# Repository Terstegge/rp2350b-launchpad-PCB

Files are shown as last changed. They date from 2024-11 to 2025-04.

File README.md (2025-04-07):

# RP2350 Launchpad

This repository contains the KiCad design files for a TI-style Launchpad
board with the RP2350B microcontroller. The board has the following
features:

- RP2350 microcontroller with 48 GPIOs (8 of these can be used as ADC inputs)
- 8MB of flash and 8MB of PSRAM
- A single red LED (connected to GPIO 38). Can be disabled with a jumper.
- Eight WS2812 RGB LEDs (connected to GPIO 39)
- A reset button
- Two user buttons (S1/S2 connected to GPIO 28/29)
- USB-C socket connected to the target RP2350
- A small button to let the RP2350 start in mass-storage mode for programming.
  This is usually not needed when using the debugger.
- A target isolation jumper block which can be used to completely disconnect
  the targer from power supply and debugging signals.
- A RP2040-based picoprobe debug probe which also forwards UART traffic from
  the target to the connected PC. Three LEDs signal UART RX/TX activity
  and SWD activity.
- Additional header for unused GPIOs of the picoprobe RP2040, which could
  be used for logic analyzer inputs or other purposes.
- Flexible power supply by either using
  * the upper USB-C socket connected to the debugger
  * a connected 3,7V LiPo battery
  * the lower USB-C socket connected to the target

  These three options are selectble with a small switch
- Integrated LiPo charger. The battery will be charged when the board is
  powered from the upper USB-C socket. Charging is signalled with a LED.
  The battery voltage can be read by the RP2350 using ADC channel 7.
- In all power scenarios, 3.3V and 5V are available. When using the
  battery as the power source, the 5V supply is generated with a step-up
  converter.

Why was this board designed? I have been using the MSP432 Launchpad from TI for
quite a while in university classes teaching microcontroller technology.
Unfortunately TI has stopped producing all MSP432-related products. Still we
have lots of TI boosterpack-boards like the Educational Boosterpack MK II.
To be able to use these Boosterpacks also in the future, a new Launchpad had
to be found or designed. The RP2350B is a very interesting microcontroller,
and, what is quite important for educational purposes, it has excellent
documentation. So this board came to life. As far as I know this is the only
RP2350 board including a picoprobe debugger, which makes programming for the
students a lot easier.

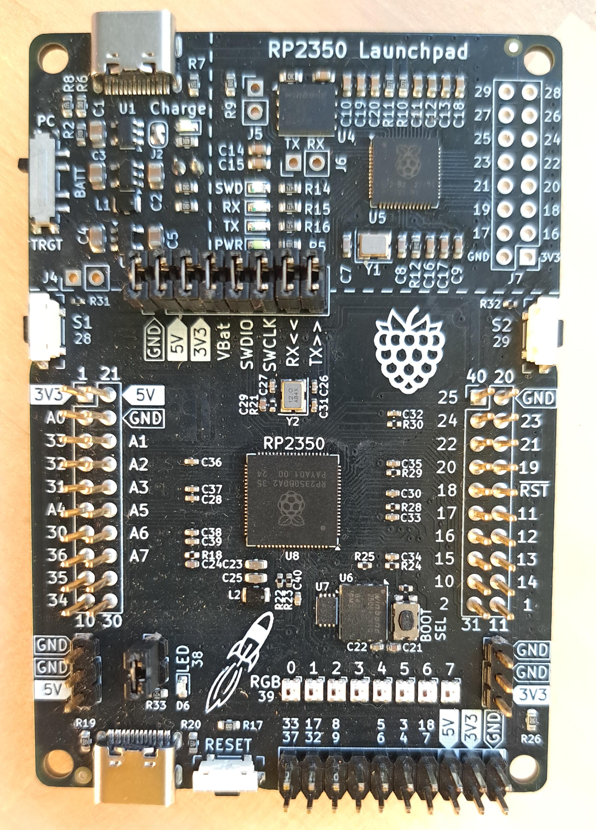
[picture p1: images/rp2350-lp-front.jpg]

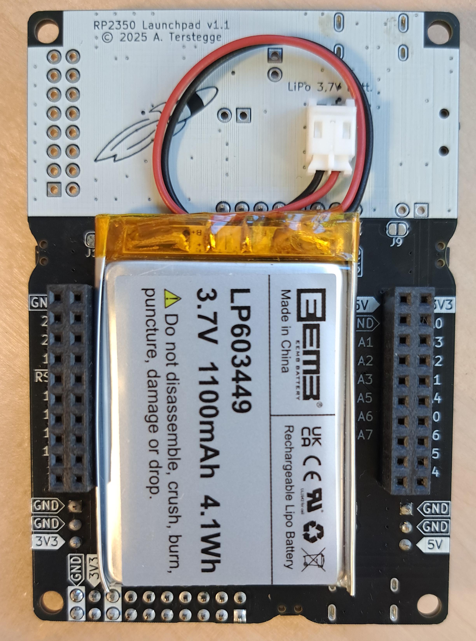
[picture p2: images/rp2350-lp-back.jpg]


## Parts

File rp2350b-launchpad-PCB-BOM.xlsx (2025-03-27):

Comment | Designator | Footprint | JLCPCB Part #
22u | C1,C2,C3,C4,C5 | Capacitor_SMD:C_0805_2012Metric | C45783
100nF | C6,C9,C10,C14,C15,C16,C17,C18,C19,C20 | Capacitor_SMD:C_0603_1608Metric | C14663
15pF | C7,C8 | Capacitor_SMD:C_0603_1608Metric | C1644
1uF | C11,C12,C13 | Capacitor_SMD:C_0603_1608Metric | C15849
4u7 | C21,C24,C29 | Capacitor_SMD:C_0402_1005Metric | C23733
100nF | C22,C28,C30,C31,C32,C33,C34,C35,C36,C37,C38,C39,C40 | Capacitor_SMD:C_0402_1005Metric | C1525
4u7 | C23,C25 | Capacitor_SMD:C_0603_1608Metric | C19666
15pF | C26,C27 | Capacitor_SMD:C_0402_1005Metric | C1548
Charge | D1 | LED_SMD:LED_0603_1608Metric | C84269
PWR | D2 | LED_SMD:LED_0603_1608Metric | C84269
LED BLUE | D3 | LED_SMD:LED_0603_1608Metric | C2288
LED GREEN | D4 | LED_SMD:LED_0603_1608Metric | C12624
LED RED | D5 | LED_SMD:LED_0603_1608Metric | C2286
LED | D6 | LED_SMD:LED_0603_1608Metric | C2286
4u7 | L1,L2 | rp2350b-launchpad-PCB:AOTA-B201610S3R3-101-T | C42411119
2k | R1,R2,R5 | Resistor_SMD:R_0603_1608Metric | C22975
100k | R3,R4,R6,R17 | Resistor_SMD:R_0603_1608Metric | C25803
5k1 | R7,R8,R19,R20 | Resistor_SMD:R_0603_1608Metric | C23186
1k | R9,R12 | Resistor_SMD:R_0603_1608Metric | C21190
27 | R10,R11 | Resistor_SMD:R_0603_1608Metric | C25190
10k | R13,R26 | Resistor_SMD:R_0603_1608Metric | C25804
470 | R14,R15,R16,R33 | Resistor_SMD:R_0603_1608Metric | C23179
33 | R18 | Resistor_SMD:R_0402_1005Metric | C25161
1k | R21,R27,R28,R29,R30,R31,R32 | Resistor_SMD:R_0402_1005Metric | C11702
27 | R22,R23 | Resistor_SMD:R_0402_1005Metric | C137890
10k | R24,R25 | Resistor_SMD:R_0402_1005Metric | C25531
S1 | S1 | rp2350b-launchpad-PCB:DIPT-1188E | C240289
S2 | S2 | rp2350b-launchpad-PCB:DIPT-1188E | C240289
Power Select | SW1 | rp2350b-launchpad-PCB:PCM13SMTR | C221842
RESET | SW2 | rp2350b-launchpad-PCB:DIPT-1188E | C240289
BOOT | SW3 | rp2350b-launchpad-PCB:KMR2-Switch | C221680
MCP73831 | U1 | Package_TO_SOT_SMD:SOT-23-5 | C424093
XC9142B50C | U2 | Package_TO_SOT_SMD:SOT-23-5 | C2468807
XC6220B33 | U3 | Package_TO_SOT_SMD:SOT-23-5 | C22466451
25Q32 | U4 | Package_SON:WSON-8-1EP_6x5mm_P1.27mm_EP3.4x4.3mm | C571260
RP2040 | U5 | Package_DFN_QFN:QFN-56-1EP_7x7mm_P0.4mm_EP3.2x3.2mm | C2040
25Q64 | U6 | Package_SON:WSON-8-1EP_6x5mm_P1.27mm_EP3.4x4.3mm | C2940197
APS6404L-3SQR | U7 | Package_SON:Winbond_USON-8-1EP_3x2mm_P0.5mm_EP0.2x1.6mm | C3040877
RP2350_80QFN | U8 | Package_DFN_QFN:QFN-80-1EP_10x10mm_P0.4mm_EP3.4x3.4mm_ThermalVias | C42415655
WS2812B-2020 | U9,U10,U11,U12,U13,U14,U15,U16 | rp2350b-launchpad-PCB:WS2812B-2020 | C965555
USB-C Connector | USB1,USB2 | rp2350b-launchpad-PCB:GT-USB-7010B | C2837092
12MHz | Y1,Y2 | Crystal:Crystal_SMD_Abracon_ABM8AIG-4Pin_3.2x2.5mm | C20625731

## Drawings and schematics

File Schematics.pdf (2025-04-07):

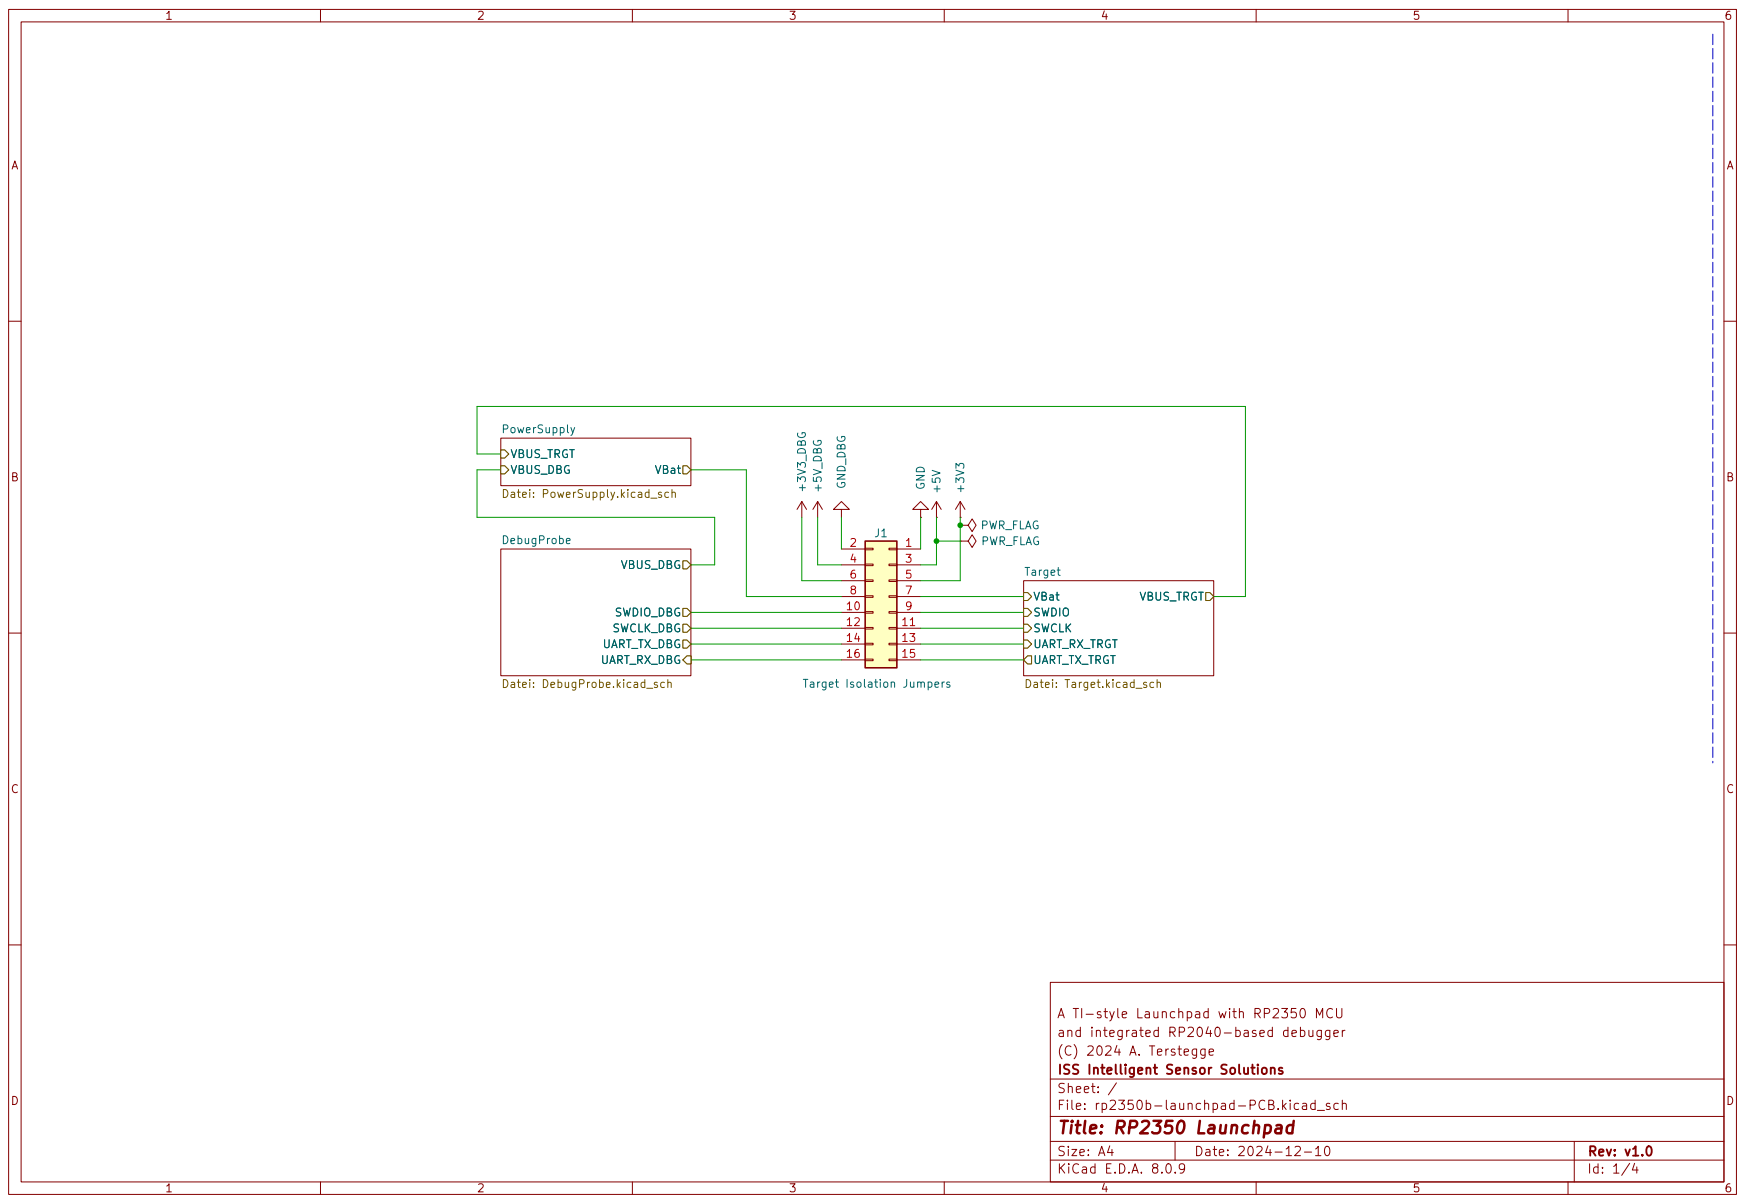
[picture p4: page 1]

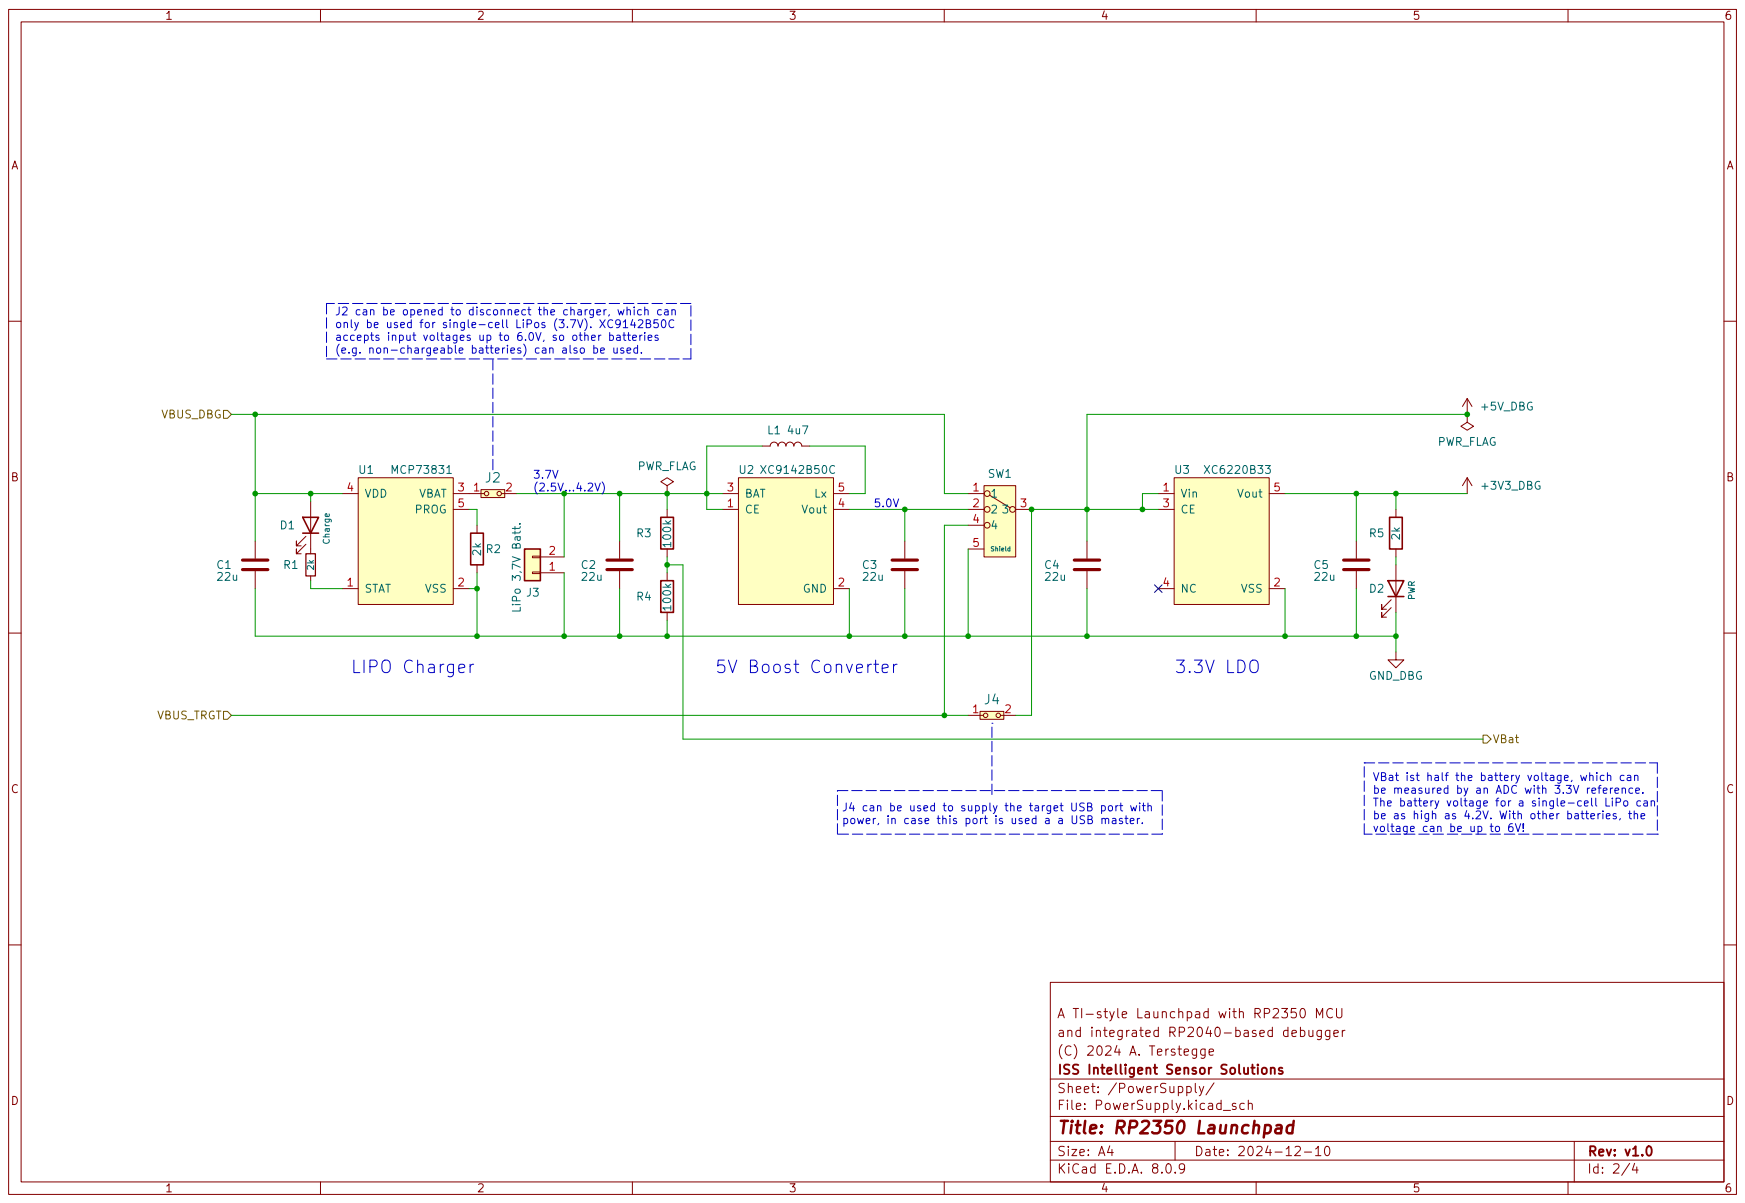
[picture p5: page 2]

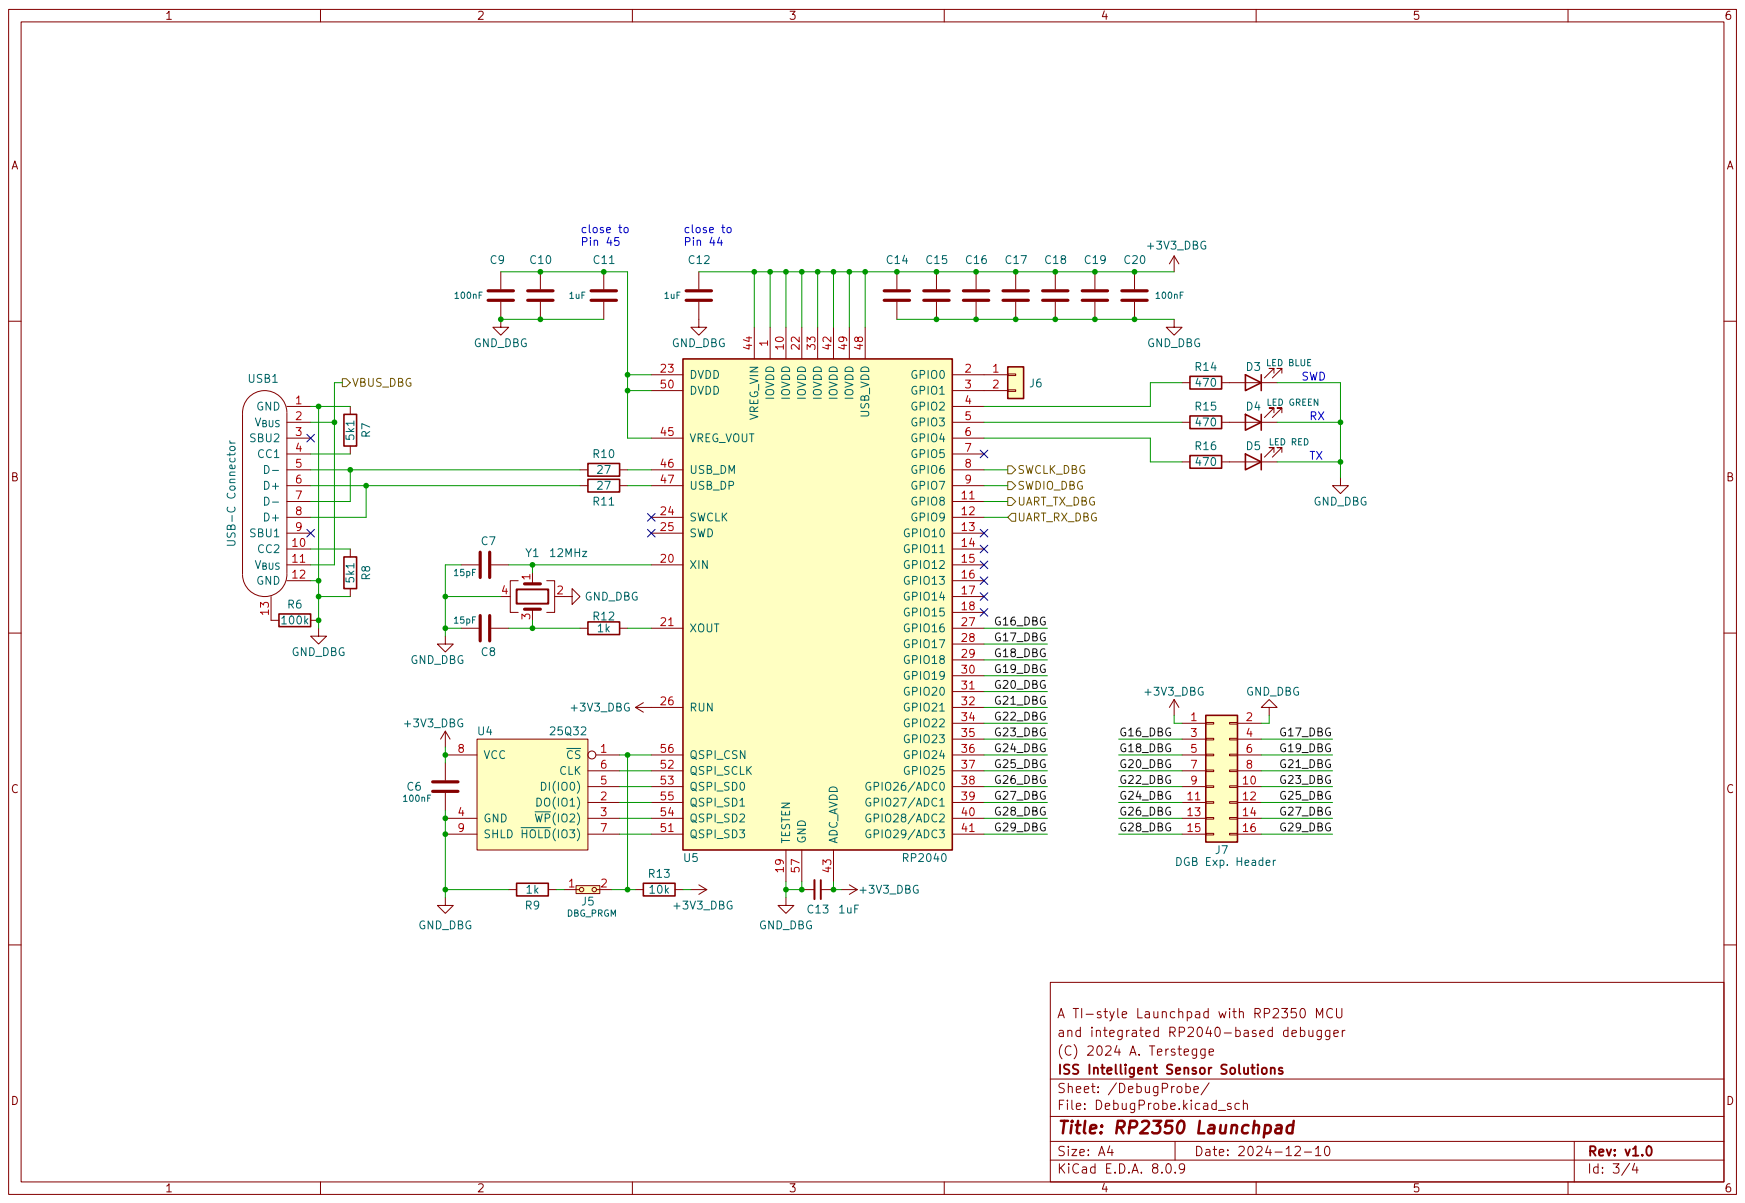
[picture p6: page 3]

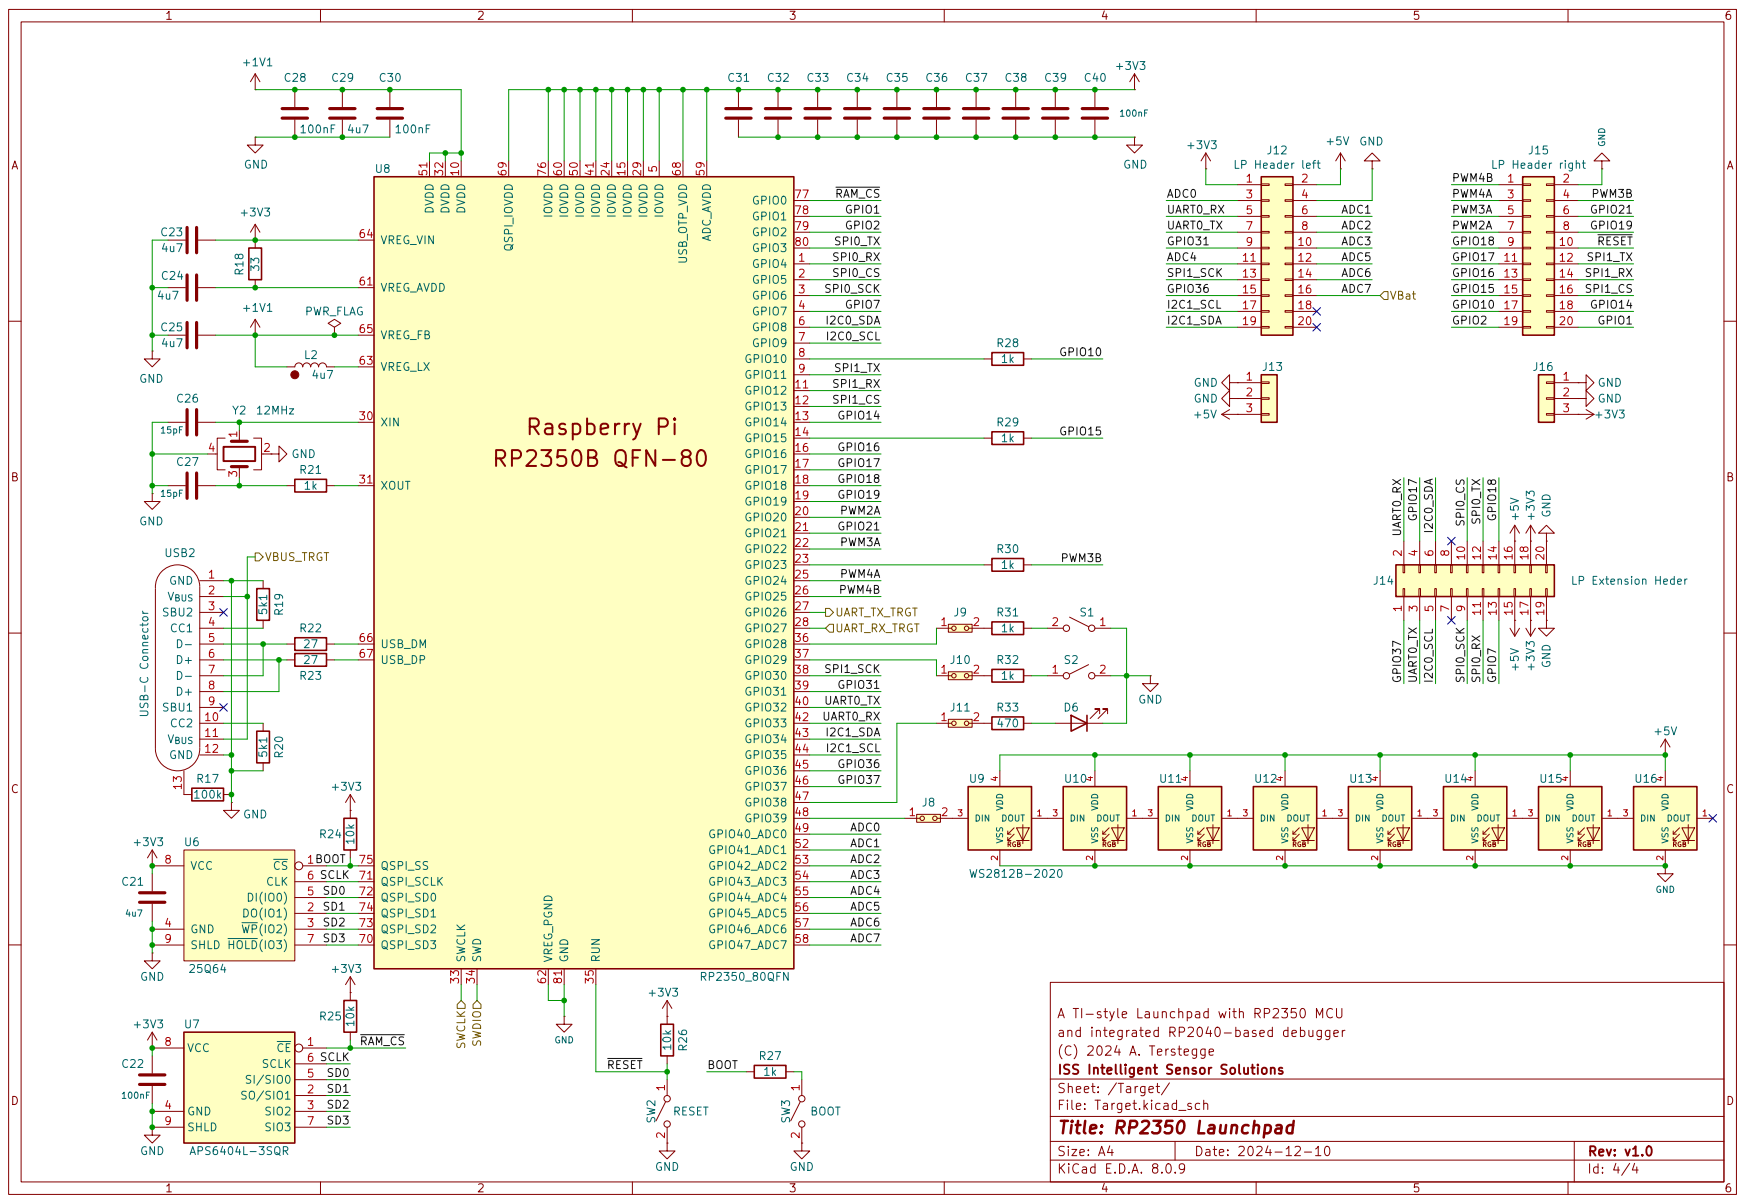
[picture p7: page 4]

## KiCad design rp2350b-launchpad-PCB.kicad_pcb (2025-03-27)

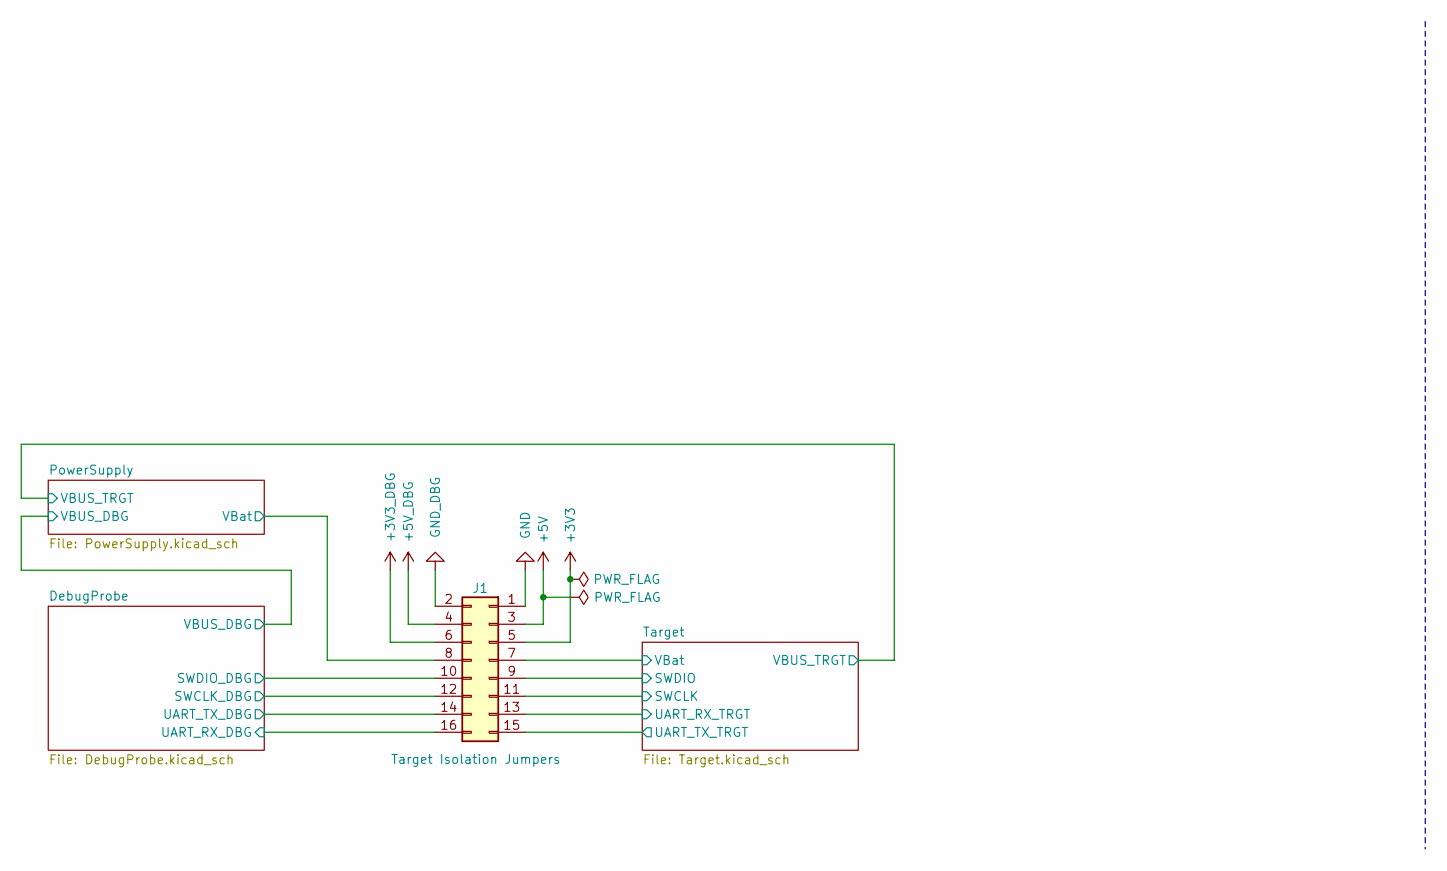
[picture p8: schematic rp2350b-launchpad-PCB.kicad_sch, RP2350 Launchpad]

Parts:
J1: Target Isolation Jumpers; PinHeader_2x08_P2.54mm_Vertical

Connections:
+3V3: J1.5; also elsewhere on the board
+3V3_DBG: J1.6; also elsewhere on the board
+5V: J1.3; also elsewhere on the board
+5V_DBG: J1.4; also elsewhere on the board
/DebugProbe/SWCLK_DBG: J1.12; also elsewhere on the board
/DebugProbe/SWDIO_DBG: J1.10; also elsewhere on the board
/DebugProbe/UART_RX_DBG: J1.16; also elsewhere on the board
/DebugProbe/UART_TX_DBG: J1.14; also elsewhere on the board
/PowerSupply/VBat: J1.8; also elsewhere on the board
/Target/ADC7: J1.7; also elsewhere on the board
/Target/SWCLK: J1.11; also elsewhere on the board
/Target/SWDIO: J1.9; also elsewhere on the board
/Target/UART_RX_TRGT: J1.13; also elsewhere on the board
/Target/UART_TX_TRGT: J1.15; also elsewhere on the board
GND: J1.1; also elsewhere on the board
GND_DBG: J1.2; also elsewhere on the board

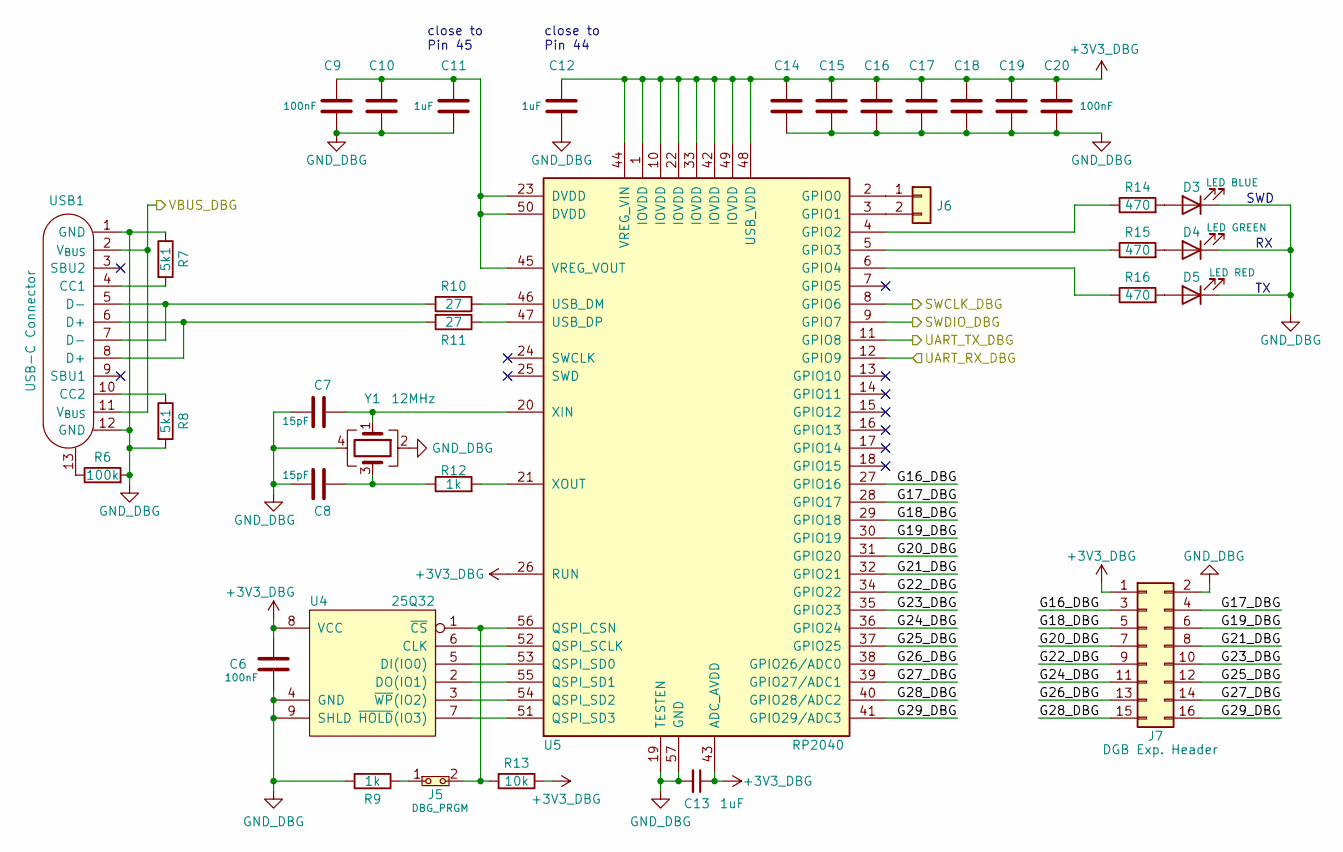
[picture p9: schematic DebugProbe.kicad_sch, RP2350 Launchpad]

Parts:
C6, C9, C10, C14, C15, C16, C17, C18, C19, C20: 100nF; C_0603_1608Metric; JLCPCB Part # C14663
C7, C8: 15pF; C_0603_1608Metric; JLCPCB Part # C1644
C11, C12, C13: 1uF; C_0603_1608Metric; JLCPCB Part # C15849
D3: LED BLUE; LED_0603_1608Metric; JLCPCB Part # C2288
D4: LED GREEN; LED_0603_1608Metric; JLCPCB Part # C12624
D5: LED RED; LED_0603_1608Metric; JLCPCB Part # C2286
J5: DBG_PRGM; PinHeader_1x02_P2.54mm_Vertical
J6: UART_DBG; PinHeader_1x02_P2.54mm_Vertical
J7: DGB Exp. Header; PinHeader_2x08_P2.54mm_Vertical
R6: 100k; R_0603_1608Metric; JLCPCB Part # C25803
R7, R8: 5k1; R_0603_1608Metric; JLCPCB Part # C23186
R9, R12: 1k; R_0603_1608Metric; JLCPCB Part # C21190
R10, R11: 27; R_0603_1608Metric; JLCPCB Part # C25190
R13: 10k; R_0603_1608Metric; JLCPCB Part # C25804
R14, R15, R16: 470; R_0603_1608Metric; JLCPCB Part # C23179
U4: 25Q32; WSON-8-1EP_6x5mm_P1.27mm_EP3.4x4.3mm; JLCPCB Part # C571260
U5: RP2040; QFN-56-1EP_7x7mm_P0.4mm_EP3.2x3.2mm; PARTREV 1.6.1; JLCPCB Part # C2040
USB1: USB-C Connector; GT-USB-7010B; JLCPCB Part # C2837092
Y1: 12MHz; Crystal_SMD_Abracon_ABM8AIG-4Pin_3.2x2.5mm; JLCPCB Part # C20625731

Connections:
+3V3_DBG: C6.1, C12.1, C13.1, C14.1, C15.1, C16.1, C17.1, C18.1, C19.1, C20.1, J7.1, R13.1, U4.8 (VCC), U5.1 (IOVDD), U5.10 (IOVDD), U5.22 (IOVDD), U5.26 (RUN), U5.33 (IOVDD), U5.42 (IOVDD), U5.43 (ADC_AVDD), U5.44 (VREG_VIN), U5.48 (USB_VDD), U5.49 (IOVDD); also elsewhere on the board
/DebugProbe/G16_DBG: J7.3, U5.27 (GPIO16)
/DebugProbe/G17_DBG: J7.4, U5.28 (GPIO17)
/DebugProbe/G18_DBG: J7.5, U5.29 (GPIO18)
/DebugProbe/G19_DBG: J7.6, U5.30 (GPIO19)
/DebugProbe/G20_DBG: J7.7, U5.31 (GPIO20)
/DebugProbe/G21_DBG: J7.8, U5.32 (GPIO21)
/DebugProbe/G22_DBG: J7.9, U5.34 (GPIO22)
/DebugProbe/G23_DBG: J7.10, U5.35 (GPIO23)
/DebugProbe/G24_DBG: J7.11, U5.36 (GPIO24)
/DebugProbe/G25_DBG: J7.12, U5.37 (GPIO25)
/DebugProbe/G26_DBG: J7.13, U5.38 (GPIO26/ADC0)
/DebugProbe/G27_DBG: J7.14, U5.39 (GPIO27/ADC1)
/DebugProbe/G28_DBG: J7.15, U5.40 (GPIO28/ADC2)
/DebugProbe/G29_DBG: J7.16, U5.41 (GPIO29/ADC3)
/DebugProbe/SWCLK_DBG: U5.8 (GPIO6); also elsewhere on the board
/DebugProbe/SWDIO_DBG: U5.9 (GPIO7); also elsewhere on the board
/DebugProbe/UART_RX_DBG: U5.12 (GPIO9); also elsewhere on the board
/DebugProbe/UART_TX_DBG: U5.11 (GPIO8); also elsewhere on the board
/DebugProbe/VBUS_DBG: USB1.2 (V_{BUS}), USB1.11 (V_{BUS}); also elsewhere on the board
GND_DBG: C6.2, C7.1, C8.1, C9.2, C10.2, C11.2, C12.2, C13.2, C14.2, C15.2, C16.2, C17.2, C18.2, C19.2, C20.2, D3.1 (K), D4.1 (K), D5.1 (K), J7.2, R6.2, R7.1, R8.2, R9.2, U4.4 (GND), U4.9 (SHLD), U5.19 (TESTEN), U5.57 (GND), USB1.1 (GND), USB1.12 (GND), Y1.2, Y1.4; also elsewhere on the board
unnamed: C8.2, R12.1, Y1.3
unnamed: D3.2 (A), R14.2
unnamed: D4.2 (A), R15.2
unnamed: D5.2 (A), R16.2
unnamed: J5.1, R9.1
unnamed: J6.1, U5.2 (GPIO0)
unnamed: J6.2, U5.3 (GPIO1)
unnamed: R6.1, USB1.13
unnamed: R10.2, USB1.5 (D-), USB1.7 (D-)
unnamed: R11.2, USB1.6 (D+), USB1.8 (D+)
unnamed: U4.6 (CLK), U5.52 (QSPI_SCLK)
unnamed: U4.5 (DI(IO0)), U5.53 (QSPI_SD0)
unnamed: U4.2 (DO(IO1)), U5.55 (QSPI_SD1)
unnamed: J5.2, R13.2, U4.1 (~CS), U5.56 (QSPI_CSN)
unnamed: U4.7 (~HOLD(IO3)), U5.51 (QSPI_SD3)
unnamed: U4.3 (~WP(IO2)), U5.54 (QSPI_SD2)
unnamed: R14.1, U5.4 (GPIO2)
unnamed: R15.1, U5.5 (GPIO3)
unnamed: R16.1, U5.6 (GPIO4)
unnamed: R10.1, U5.46 (USB_DM)
unnamed: R11.1, U5.47 (USB_DP)
unnamed: C9.1, C10.1, C11.1, U5.23 (DVDD), U5.45 (VREG_VOUT), U5.50 (DVDD)
unnamed: C7.2, U5.20 (XIN), Y1.1
unnamed: R12.2, U5.21 (XOUT)
unnamed: R7.2, USB1.4 (CC1)
unnamed: R8.1, USB1.10 (CC2)

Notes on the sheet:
SWD
close to Pin 45
close to Pin 44

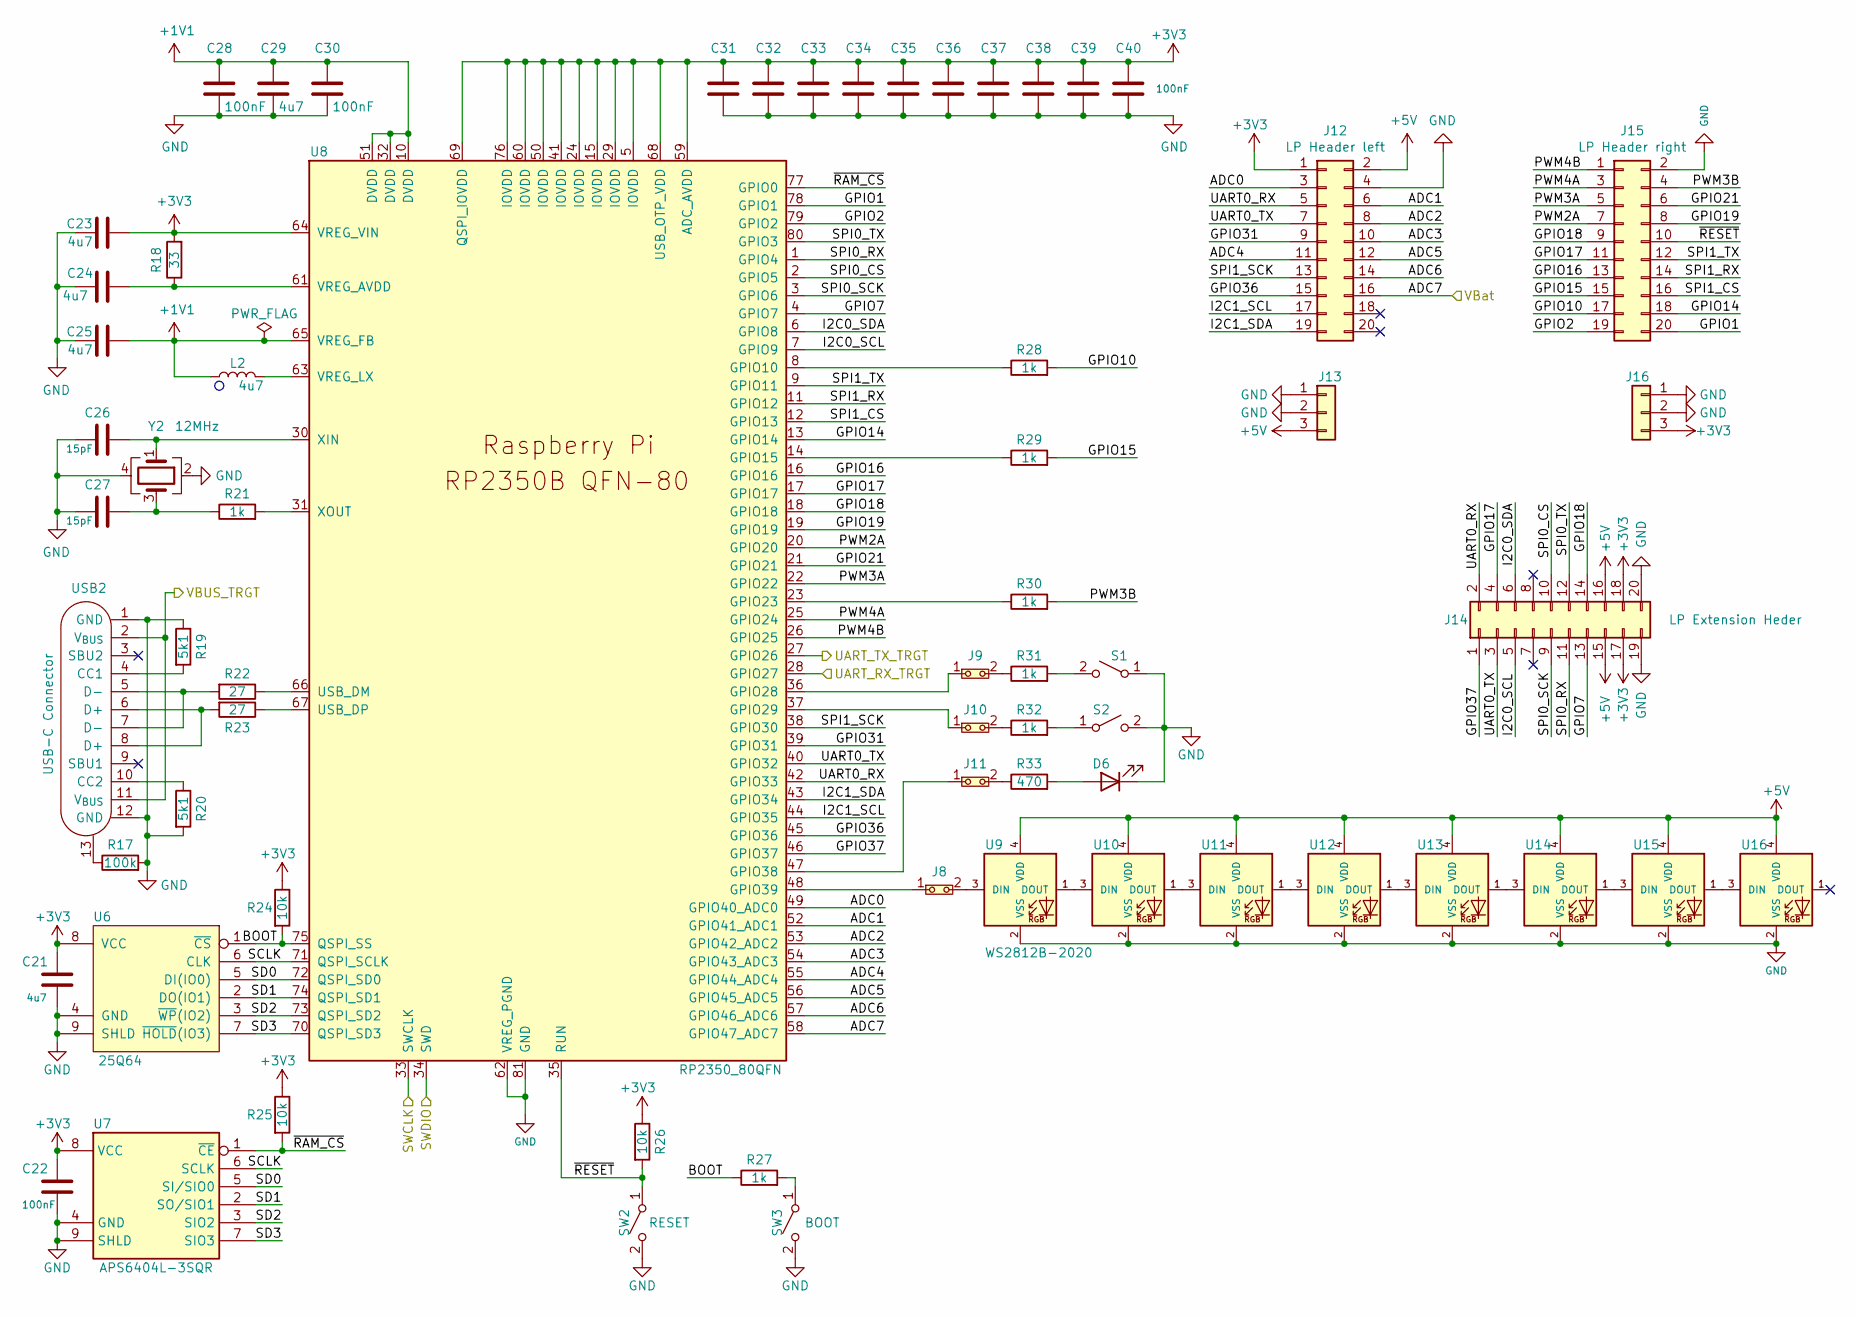
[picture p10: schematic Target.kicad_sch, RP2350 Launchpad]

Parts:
C21, C24, C29: 4u7; C_0402_1005Metric; JLCPCB Part # C23733
C22, C28, C30, C31, C32, C33, C34, C35, C36, C37, C38, C39, C40: 100nF; C_0402_1005Metric; JLCPCB Part # C1525
C23, C25: 4u7; C_0603_1608Metric; JLCPCB Part # C19666
C26, C27: 15pF; C_0402_1005Metric; JLCPCB Part # C1548
D6: LED; LED_0603_1608Metric; JLCPCB Part # C2286
J8, J9, J10: Jumper; SolderJumper-2_P1.3mm_Bridged_RoundedPad1.0x1.5mm
J11: Jumper; PinHeader_1x02_P2.54mm_Vertical
J12: LP Header left; PinHeader_2x10_P2.54mm_Vertical
J13, J16: PWR Header; PinHeader_1x03_P2.54mm_Vertical
J14: LP Extension Heder; PinHeader_2x10_P2.54mm_Vertical
J15: LP Header right; PinHeader_2x10_P2.54mm_Vertical
L2: 4u7; AOTA-B201610S3R3-101-T; JLCPCB Part # C42411119
R17: 100k; R_0603_1608Metric; JLCPCB Part # C25803
R18: 33; R_0402_1005Metric; JLCPCB Part # C25161
R19, R20: 5k1; R_0603_1608Metric; JLCPCB Part # C23186
R21, R27, R28, R29, R30, R31, R32: 1k; R_0402_1005Metric; JLCPCB Part # C11702
R22, R23: 27; R_0402_1005Metric; JLCPCB Part # C137890
R24, R25: 10k; R_0402_1005Metric; JLCPCB Part # C25531
R26: 10k; R_0603_1608Metric; JLCPCB Part # C25804
R33: 470; R_0603_1608Metric; JLCPCB Part # C23179
S1: S1; DIPT-1188E; JLCPCB Part # C240289
S2: S2; DIPT-1188E; JLCPCB Part # C240289
SW2: RESET; DIPT-1188E; JLCPCB Part # C240289
SW3: BOOT; KMR2-Switch; JLCPCB Part # C221680
U6: 25Q64; WSON-8-1EP_6x5mm_P1.27mm_EP3.4x4.3mm; JLCPCB Part # C2940197
U7: APS6404L-3SQR; Winbond_USON-8-1EP_3x2mm_P0.5mm_EP0.2x1.6mm; JLCPCB Part # C3040877
U8: RP2350_80QFN; QFN-80-1EP_10x10mm_P0.4mm_EP3.4x3.4mm_ThermalVias; JLCPCB Part # C42415655
U9, U10, U11, U12, U13, U14, U15, U16: WS2812B-2020; JLCPCB Part # C965555
USB2: USB-C Connector; GT-USB-7010B; JLCPCB Part # C2837092
Y2: 12MHz; Crystal_SMD_Abracon_ABM8AIG-4Pin_3.2x2.5mm; JLCPCB Part # C20625731

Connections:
+1V1: C25.2, C28.1, C29.1, C30.1, L2.1, U8.10 (DVDD), U8.32 (DVDD), U8.51 (DVDD), U8.65 (VREG_FB)
+3V3: C21.1, C22.1, C23.2, C31.1, C32.1, C33.1, C34.1, C35.1, C36.1, C37.1, C38.1, C39.1, C40.1, J12.1, J14.17, J14.18, J16.3, R18.2, R24.1, R25.1, R26.1, U6.8 (VCC), U7.8 (VCC), U8.5 (IOVDD), U8.15 (IOVDD), U8.24 (IOVDD), U8.29 (IOVDD), U8.41 (IOVDD), U8.50 (IOVDD), U8.59 (ADC_AVDD), U8.60 (IOVDD), U8.64 (VREG_VIN), U8.68 (USB_OTP_VDD), U8.69 (QSPI_IOVDD), U8.76 (IOVDD); also elsewhere on the board
+5V: J12.2, J13.3, J14.15, J14.16, U9.4 (VDD), U10.4 (VDD), U11.4 (VDD), U12.4 (VDD), U13.4 (VDD), U14.4 (VDD), U15.4 (VDD), U16.4 (VDD); also elsewhere on the board
/PowerSupply/VBUS_TRGT: USB2.2 (V_{BUS}), USB2.11 (V_{BUS}); also elsewhere on the board
/Target/ADC0: J12.3, U8.49 (GPIO40_ADC0)
/Target/ADC1: J12.6, U8.52 (GPIO41_ADC1)
/Target/ADC2: J12.8, U8.53 (GPIO42_ADC2)
/Target/ADC3: J12.10, U8.54 (GPIO43_ADC3)
/Target/ADC4: J12.11, U8.55 (GPIO44_ADC4)
/Target/ADC5: J12.12, U8.56 (GPIO45_ADC5)
/Target/ADC6: J12.14, U8.57 (GPIO46_ADC6)
/Target/ADC7: J12.16, U8.58 (GPIO47_ADC7); also elsewhere on the board
/Target/BOOT: R24.2, R27.1, U6.1 (~CS), U8.75 (QSPI_SS)
/Target/GPIO1: J15.20, U8.78 (GPIO1)
/Target/GPIO2: J15.19, U8.79 (GPIO2)
/Target/GPIO7: J14.13, U8.4 (GPIO7)
/Target/GPIO10: J15.17, R28.2
/Target/GPIO14: J15.18, U8.13 (GPIO14)
/Target/GPIO15: J15.15, R29.2
/Target/GPIO16: J15.13, U8.16 (GPIO16)
/Target/GPIO17: J14.4, J15.11, U8.17 (GPIO17)
/Target/GPIO18: J14.14, J15.9, U8.18 (GPIO18)
/Target/GPIO19: J15.8, U8.19 (GPIO19)
/Target/GPIO21: J15.6, U8.21 (GPIO21)
/Target/GPIO31: J12.9, U8.39 (GPIO31)
/Target/GPIO36: J12.15, U8.45 (GPIO36)
/Target/GPIO37: J14.1, U8.46 (GPIO37)
/Target/I2C0_SCL: J14.5, U8.7 (GPIO9)
/Target/I2C0_SDA: J14.6, U8.6 (GPIO8)
/Target/I2C1_SCL: J12.17, U8.44 (GPIO35)
/Target/I2C1_SDA: J12.19, U8.43 (GPIO34)
/Target/PWM2A: J15.7, U8.20 (GPIO20)
/Target/PWM3A: J15.5, U8.22 (GPIO22)
/Target/PWM3B: J15.4, R30.2
/Target/PWM4A: J15.3, U8.25 (GPIO24)
/Target/PWM4B: J15.1, U8.26 (GPIO25)
/Target/SCLK: U6.6 (CLK), U7.6 (SCLK), U8.71 (QSPI_SCLK)
/Target/SD0: U6.5 (DI(IO0)), U7.5 (SI/SIO0), U8.72 (QSPI_SD0)
/Target/SD1: U6.2 (DO(IO1)), U7.2 (SO/SIO1), U8.74 (QSPI_SD1)
/Target/SD2: U6.3 (~WP(IO2)), U7.3 (SIO2), U8.73 (QSPI_SD2)
/Target/SD3: U6.7 (~HOLD(IO3)), U7.7 (SIO3), U8.70 (QSPI_SD3)
/Target/SPI0_CS: J14.10, U8.2 (GPIO5)
/Target/SPI0_RX: J14.11, U8.1 (GPIO4)
/Target/SPI0_SCK: J14.9, U8.3 (GPIO6)
/Target/SPI0_TX: J14.12, U8.80 (GPIO3)
/Target/SPI1_CS: J15.16, U8.12 (GPIO13)
/Target/SPI1_RX: J15.14, U8.11 (GPIO12)
/Target/SPI1_SCK: J12.13, U8.38 (GPIO30)
/Target/SPI1_TX: J15.12, U8.9 (GPIO11)
/Target/SWCLK: U8.33 (SWCLK); also elsewhere on the board
/Target/SWDIO: U8.34 (SWD); also elsewhere on the board
/Target/UART0_RX: J12.5, J14.2, U8.42 (GPIO33)
/Target/UART0_TX: J12.7, J14.3, U8.40 (GPIO32)
/Target/UART_RX_TRGT: U8.28 (GPIO27); also elsewhere on the board
/Target/UART_TX_TRGT: U8.27 (GPIO26); also elsewhere on the board
/Target/~RAM_CS: R25.2, U7.1 (~CE), U8.77 (GPIO0)
/Target/~RESET: J15.10, R26.2, SW2.1 (A), U8.35 (RUN)
GND: C21.2, C22.2, C23.1, C24.2, C25.1, C26.1, C27.1, C28.2, C29.2, C30.2, C31.2, C32.2, C33.2, C34.2, C35.2, C36.2, C37.2, C38.2, C39.2, C40.2, D6.1 (K), J12.4, J13.1, J13.2, J14.19, J14.20, J15.2, J16.1, J16.2, R17.2, R19.1, R20.2, S1.1 (A), S2.2 (B), SW2.2 (B), SW3.2 (B), U6.4 (GND), U6.9 (SHLD), U7.4 (GND), U7.9 (SHLD), U8.62 (VREG_PGND), U8.81 (GND), U9.2 (VSS), U10.2 (VSS), U11.2 (VSS), U12.2 (VSS), U13.2 (VSS), U14.2 (VSS), U15.2 (VSS), U16.2 (VSS), USB2.1 (GND), USB2.12 (GND), Y2.2, Y2.4; also elsewhere on the board
unnamed: C27.2, R21.1, Y2.3
unnamed: D6.2 (A), R33.2
unnamed: J9.2, R31.1
unnamed: J10.2, R32.1
unnamed: J11.2, R33.1
unnamed: R17.1, USB2.13
unnamed: R22.2, USB2.5 (D-), USB2.7 (D-)
unnamed: R23.2, USB2.6 (D+), USB2.8 (D+)
unnamed: R31.2, S1.2 (B)
unnamed: R32.2, S2.1 (A)
unnamed: R27.2, SW3.1 (A)
unnamed: R28.1, U8.8 (GPIO10)
unnamed: R29.1, U8.14 (GPIO15)
unnamed: R30.1, U8.23 (GPIO23)
unnamed: J9.1, U8.36 (GPIO28)
unnamed: J10.1, U8.37 (GPIO29)
unnamed: J11.1, U8.47 (GPIO38)
unnamed: J8.1, U8.48 (GPIO39)
unnamed: R22.1, U8.66 (USB_DM)
unnamed: R23.1, U8.67 (USB_DP)
unnamed: C24.1, R18.1, U8.61 (VREG_AVDD)
unnamed: L2.2, U8.63 (VREG_LX)
unnamed: C26.2, U8.30 (XIN), Y2.1
unnamed: R21.2, U8.31 (XOUT)
unnamed: J8.2, U9.3 (DIN)
unnamed: U9.1 (DOUT), U10.3 (DIN)
unnamed: U10.1 (DOUT), U11.3 (DIN)
unnamed: U11.1 (DOUT), U12.3 (DIN)
unnamed: U12.1 (DOUT), U13.3 (DIN)
unnamed: U13.1 (DOUT), U14.3 (DIN)
unnamed: U14.1 (DOUT), U15.3 (DIN)
unnamed: U15.1 (DOUT), U16.3 (DIN)
unnamed: R19.2, USB2.4 (CC1)
unnamed: R20.1, USB2.10 (CC2)

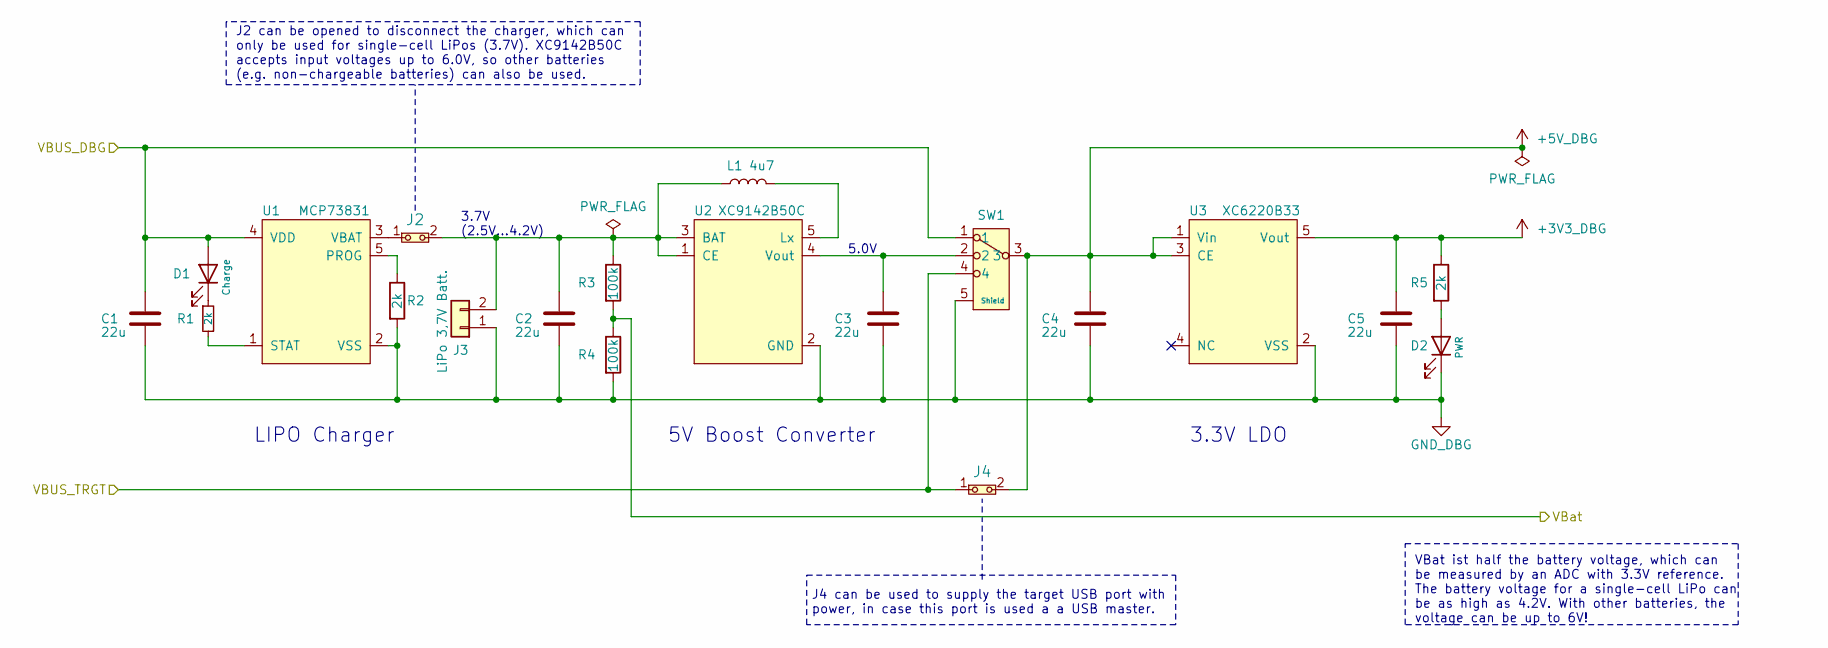
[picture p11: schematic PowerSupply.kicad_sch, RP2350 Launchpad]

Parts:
C1, C2, C3, C4, C5: 22u; C_0805_2012Metric; JLCPCB Part # C45783
D1: Charge; LED_0603_1608Metric; JLCPCB Part # C84269
D2: PWR; LED_0603_1608Metric; JLCPCB Part # C84269
J2: Jumper; SolderJumper-2_P1.3mm_Open_RoundedPad1.0x1.5mm
J3: LiPo 3,7V Batt.; JST-S2B-PH-KL
J4: Jumper; PinHeader_1x02_P2.54mm_Vertical
L1: 4u7; AOTA-B201610S3R3-101-T; JLCPCB Part # C42411119
R1, R2, R5: 2k; R_0603_1608Metric; JLCPCB Part # C22975
R3, R4: 100k; R_0603_1608Metric; JLCPCB Part # C25803
SW1: Power Select; PCM13SMTR; JLCPCB Part # C221842
U1: MCP73831; SOT-23-5; JLCPCB Part # C424093
U2: XC9142B50C; SOT-23-5; JLCPCB Part # C2468807
U3: XC6220B33; SOT-23-5; JLCPCB Part # C22466451

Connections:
+3V3_DBG: C5.2, R5.1, U3.5 (Vout); also elsewhere on the board
+5V_DBG: C4.2, J4.2, SW1.3, U3.1 (Vin), U3.3 (CE); also elsewhere on the board
/DebugProbe/VBUS_DBG: C1.2, D1.2 (A), SW1.1, U1.4 (VDD); also elsewhere on the board
/PowerSupply/VBUS_TRGT: J4.1, SW1.4; also elsewhere on the board
/PowerSupply/VBat: R3.2, R4.1; also elsewhere on the board
GND_DBG: C1.1, C2.1, C3.1, C4.1, C5.1, D2.1 (K), J3.1, R2.2, R4.2, SW1.5 (Shield), U1.2 (VSS), U2.2 (GND), U3.2 (VSS); also elsewhere on the board
unnamed: D1.1 (K), R1.1
unnamed: D2.2 (A), R5.2
unnamed: C2.2, J2.2, J3.2, L1.1, R3.1, U2.1 (CE), U2.3 (BAT)
unnamed: R2.1, U1.5 (PROG)
unnamed: R1.2, U1.1 (STAT)
unnamed: J2.1, U1.3 (VBAT)
unnamed: L1.2, U2.5 (Lx)
unnamed: C3.2, SW1.2, U2.4 (Vout)

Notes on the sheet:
3.7V (2.5V...4.2V)
3.3V LDO
5V Boost Converter
VBat ist half the battery voltage, which can be measured by an ADC with 3.3V reference. The battery voltage for a single-cell LiPo can be as high as 4.2V. With other batteries, the voltage can be up to 6V!
J4 can be used to supply the target USB port with power, in case this port is used a a USB master.
LIPO Charger
J2 can be opened to disconnect the charger, which can only be used for single-cell LiPos (3.7V). XC9142B50C accepts input voltages up to 6.0V, so other batteries (e.g. non-chargeable batteries) can also be used.
5.0V

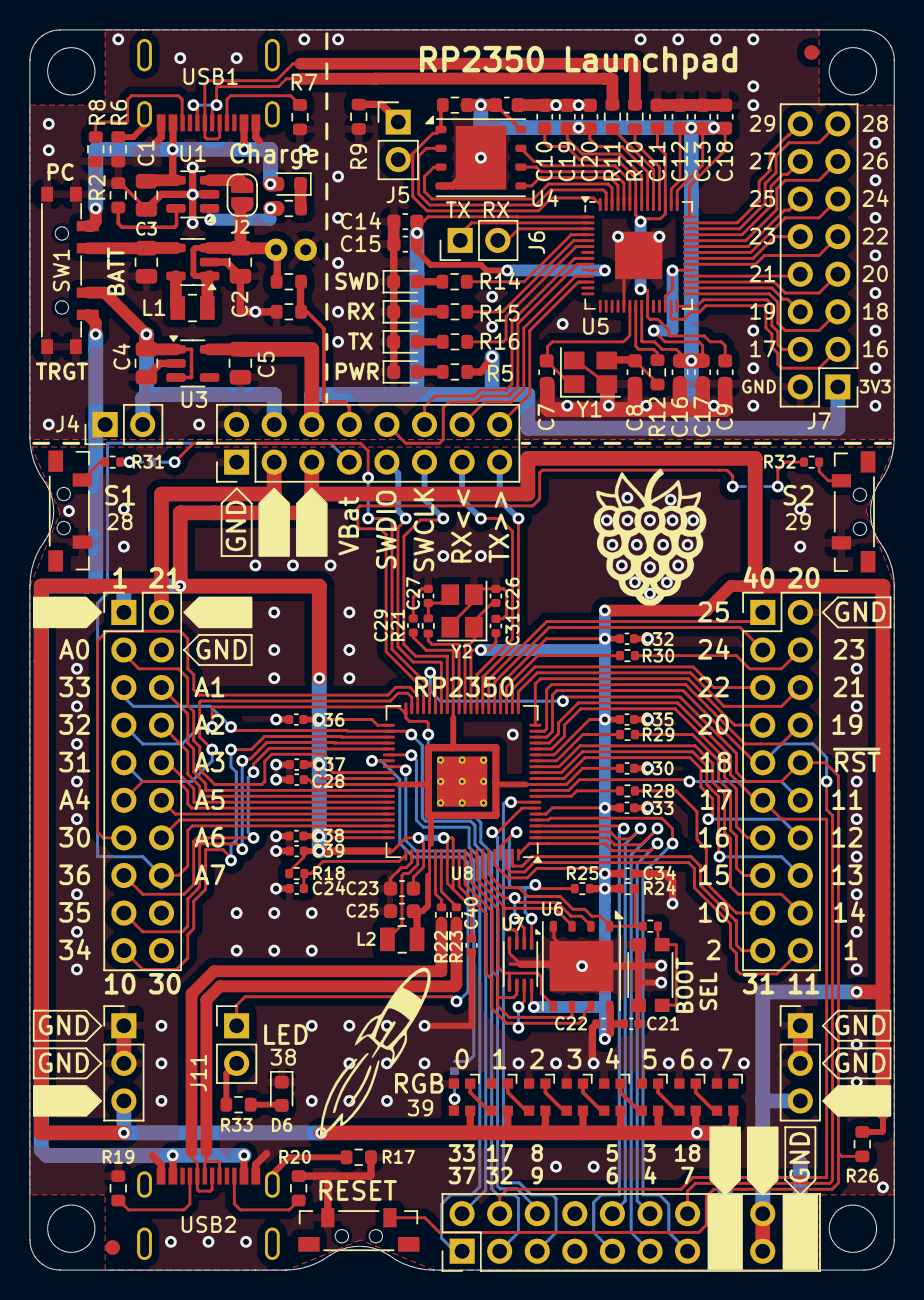
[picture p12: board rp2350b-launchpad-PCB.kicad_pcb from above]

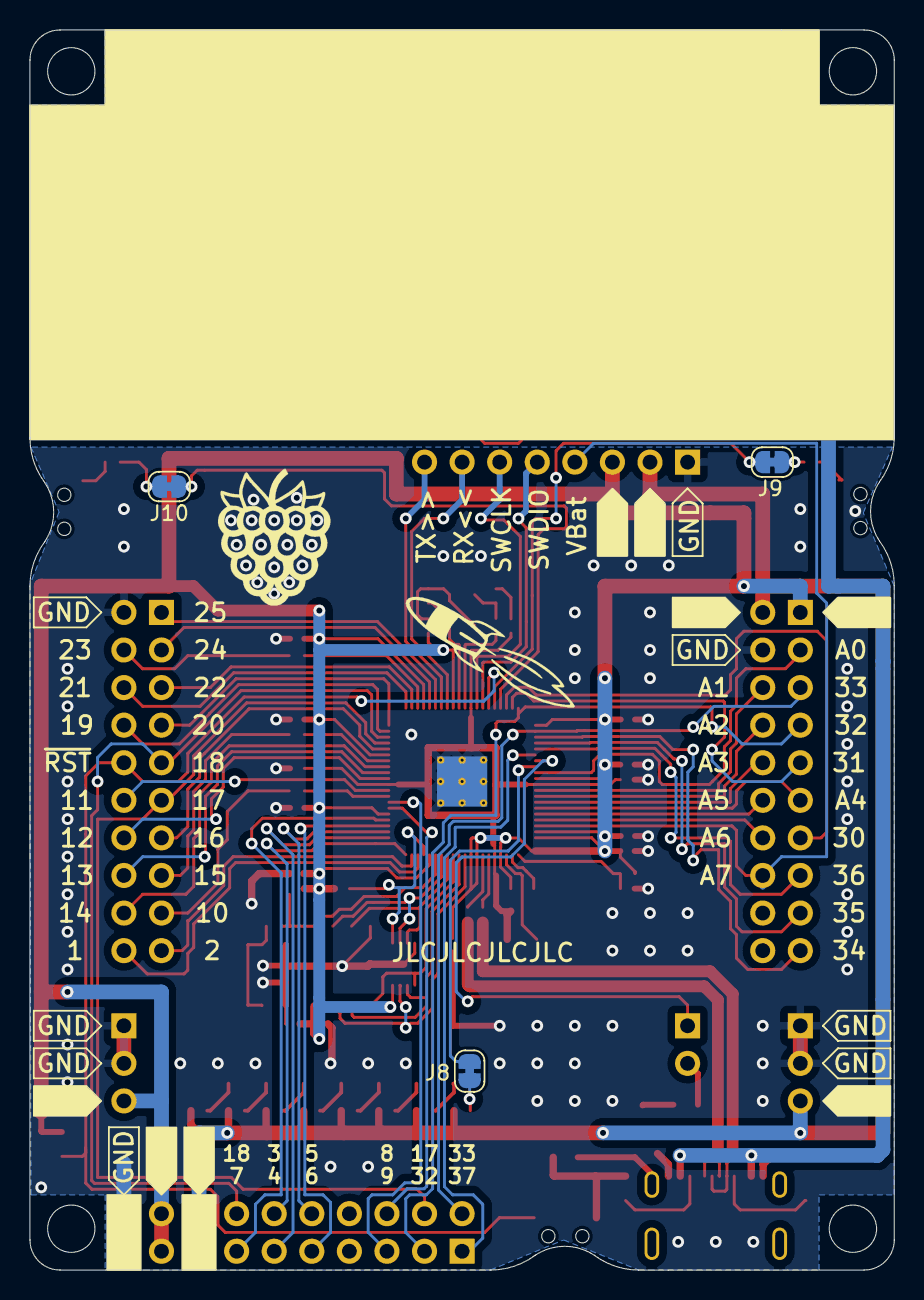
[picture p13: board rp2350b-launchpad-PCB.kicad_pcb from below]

Board: 2 copper layers, 58.4 x 83.8 mm, 122 parts (4 on the bottom side), 149 nets.

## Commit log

2024-11-22 First version of RP2350B Launchpad finished!
    [BOM-Kuttig.ods, BOM.ods, BOM1.ods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]
2024-11-22 small change to PCB (GND area under MCU).
    [rp2040-launchpad-PCB.kicad_pcb]
2024-11-22 Renamed files.
    [BOM-Kuttig.ods, BOM.ods, BOM1.ods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]
2024-11-22 Fixes to manual renaming...
    [Target.kicad_sch, rp2350b-launchpad-PCB.kicad_pcb]
2024-11-22 More fixes...
    [DebugProbe.kicad_sch, PowerSupply.kicad_sch]
2024-11-22 Changed target flash to 16 MiB type.
    [rp2350b-launchpad-PCB.kicad_pcb]
2024-11-22 Footprint cleanup.
    [DebugProbe.kicad_sch, PowerSupply.kicad_sch, rp2350b-launchpad-PCB.kicad_pcb]
2024-11-22 Fixed gerber file names.
    [Target.kicad_sch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]
2024-11-23 Renumbering parts on target.
    [Target.kicad_sch, rp2350b-launchpad-PCB.kicad_pcb]
2025-01-09 Ready for Version v1.0. Changed PCB to comply with RPi design 'rules'. Without using special components and PCB designs, the PCB may not be produced :\
    [DebugProbe.kicad_sch, PowerSupply.kicad_sch, Target.kicad_sch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]
2025-02-11 Updated BOM and pos files for v1.0
    [rp2350b-launchpad-PCB-BOM.csv, rp2350b-launchpad-PCB-BOM.xlsx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]
2025-02-13 Updates for better JLCPCB processing. Version is now 1.1
    [DebugProbe.kicad_sch, PowerSupply.kicad_sch, Target.kicad_sch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]
2025-02-22 Ready for v1.1
    [PowerSupply.kicad_sch, Target.kicad_sch, rp2350b-launchpad-PCB-BOM.xlsx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]
2025-03-27 Last small fixes for v1.11
    [PowerSupply.kicad_sch, rp2350b-launchpad-PCB-BOM.xlsx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]
2025-04-07 Added battery volatage reading in README.

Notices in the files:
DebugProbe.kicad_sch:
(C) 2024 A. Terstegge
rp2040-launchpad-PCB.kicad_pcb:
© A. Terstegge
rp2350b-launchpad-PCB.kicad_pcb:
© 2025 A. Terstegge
